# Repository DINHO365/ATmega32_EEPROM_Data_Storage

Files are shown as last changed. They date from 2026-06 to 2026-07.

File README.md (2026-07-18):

# ATmega32 EEPROM Data Logging and Configuration Storage System

Demonstrates internal EEPROM read/write on the ATmega32 by letting a
user increment/decrement a value in RAM, save it to EEPROM, read it
back, clear it, and recover it after reset or a power cycle.

## Repository structure

```
ATmega32_EEPROM_Data_Storage/
├── README.md
├── firmware/
│   ├── src/        button.c, display.c, eeprom_storage.c, indicator.c, lcd.c, main.c, uart.c
│   ├── include/    matching headers + config.h
│   └── hex/        firmware.hex / firmware.elf
├── kicad/
│   ├── schematic/  ATmega32_EEPROM_Storage.kicad_sch (+ project files), rendered PDF
│   ├── pcb/        ATmega32_EEPROM_Storage.kicad_pcb (+ project files), rendered PDF
│   └── gerber/     Gerber + drill (.drl) output
├── simulide/
│   ├── circuit/     EEPROM_Storage.sim1
│   └── screenshots/ test-run screenshots
├── documentation/
│   ├── block_diagram.png
│   ├── flowchart.png
│   ├── pin_mapping_table.md
│   ├── eeprom_address_table.md
│   ├── test_results.md
│   ├── erc_report.txt
│   └── drc_report.txt
└── media/
    └── demonstration_video.mp4
```

The schematic and PCB are kept in separate `kicad/schematic/` and
`kicad/pcb/` folders, each with its own copy of the KiCad project file
so either one opens directly in KiCad.

## Firmware

Source lives in `firmware/`, written in C for the ATmega32 at 8 MHz
(adjust `F_CPU` in `firmware/include/config.h` if a different clock is
used).

Build with avr-gcc:

```
cd firmware
make
```

(or open the `firmware/` folder as an MPLAB for VS Code project, using
the same source/include paths.)

### Behavior

| Action | Result |
|---|---|
| Power ON / OFF | Last value loaded from EEPROM and shown as CURRENT |
| INC button (PA0) | CURRENT increases (clamped at 255) |
| DEC button (PA1) | CURRENT decreases (clamped at 0) |
| SAVE button (PA2)  | CURRENT written to EEPROM; SAVE_LED + buzzer confirm |
| READ button (PA3)  | SAVED re-read from EEPROM and displayed |
| CLEAR button (PA4) | EEPROM and CURRENT reset to default (0); both LEDs + buzzer confirm |

Display output is a 16x2 HD44780 LCD (RS=PD4, RW=PD5, EN=PD6,
D4-D7=PC4-PC7 via the 16-pin header J1), showing:

```
CURRENT: 025
SAVED:   020
```

`DISPLAY_MODE` in `firmware/include/config.h` can be switched to
`DISPLAY_MODE_USART` to print the same values over USART (9600 baud,
8N1, PD1/TXD) for bench testing without an LCD attached.

### EEPROM layout

See [documentation/eeprom_address_table.md](documentation/eeprom_address_table.md).

### Pin mapping

See [documentation/pin_mapping_table.md](documentation/pin_mapping_table.md).

## SimulIDE simulation

`simulide/circuit/EEPROM_Storage.sim1` mirrors the KiCad PCB wiring
(4-bit LCD interface, RS/RW/EN on PD4-PD6, data lines on PC4-PC7) so
the same firmware behaves identically in simulation and on hardware.
Test results and screenshots for all required test cases are in
[documentation/test_results.md](documentation/test_results.md).

## KiCad design

Schematic and PCB pass ERC and DRC with no violations (see
`documentation/erc_report.txt` and `documentation/drc_report.txt`).
Gerber and drill files are in `kicad/gerber/`.

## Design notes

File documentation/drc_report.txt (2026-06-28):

** Drc report for ATmega32_EEPROM_Storage.kicad_pcb **
** Created on 2026-06-28T17:31:36 **
** Report includes: Errors, Warnings, Exclusions **

** Found 0 DRC violations **

** Found 0 unconnected pads **

** Found 0 Footprint errors **

** Ignored checks **
    - Footprint has no courtyard defined
    - Track endpoint not centered on via
    - Tuning profile track geometries
    - Footprint doesn't match symbol's footprint filters
    - Footprint component type doesn't match footprint pads

** End of Report **

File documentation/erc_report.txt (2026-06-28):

ERC report (2026-06-28T17:30:23, Encoding UTF8)
Report includes: Errors, Warnings, Exclusions

***** Sheet /

 ** ERC messages: 0  Errors 0  Warnings 0

 ** Ignored checks:
    - Global label only appears once in the schematic
    - Four connection points are joined together
    - SPICE model issue
    - Assigned footprint doesn't match footprint filters

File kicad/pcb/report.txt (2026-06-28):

Info: Processing symbol 'BZ1:Buzzer_Beeper:Buzzer_12x9.5RM7.6'.
Info: Processing symbol 'Q1:'.
Info: Processing symbol 'R4:Resistor_THT:R_Axial_DIN0207_L6.3mm_D2.5mm_P7.62mm_Horizontal'.
Info: Processing symbol 'C3:Capacitor_THT:C_Disc_D5.0mm_W2.5mm_P5.00mm'.
Info: Processing symbol 'ERROR_LED1:LED_THT:LED_D5.0mm'.
Info: Processing symbol 'R1:Resistor_THT:R_Axial_DIN0207_L6.3mm_D2.5mm_P7.62mm_Horizontal'.
Info: Processing symbol 'R3:Resistor_THT:R_Axial_DIN0207_L6.3mm_D2.5mm_P7.62mm_Horizontal'.
Info: Processing symbol 'R2:Resistor_THT:R_Axial_DIN0207_L6.3mm_D2.5mm_P7.62mm_Horizontal'.
Info: Processing symbol 'CLEAR1:Button_Switch_THT:SW_PUSH_6mm'.
Info: Processing symbol 'C2:Capacitor_THT:C_Disc_D5.0mm_W2.5mm_P5.00mm'.
Info: Processing symbol 'J1:'.
Info: Processing symbol 'C6:Capacitor_THT:C_Disc_D5.0mm_W2.5mm_P5.00mm'.
Info: Processing symbol 'D1:'.
Info: Processing symbol 'READ1:Button_Switch_THT:SW_PUSH_6mm'.
Info: Processing symbol 'C1:Capacitor_THT:C_Disc_D5.0mm_W2.5mm_P5.00mm'.
Info: Processing symbol 'C5:Capacitor_THT:C_Disc_D5.0mm_W2.5mm_P5.00mm'.
Info: Processing symbol 'DEC1:Button_Switch_THT:SW_PUSH_6mm'.
Info: Processing symbol 'INC1:Button_Switch_THT:SW_PUSH_6mm'.
Info: Processing symbol 'C4:Capacitor_THT:C_Disc_D5.0mm_W2.5mm_P5.00mm'.
Info: Processing symbol 'R5:Resistor_THT:R_Axial_DIN0207_L6.3mm_D2.5mm_P7.62mm_Horizontal'.
Info: Processing symbol 'RV1:'.
Info: Processing symbol 'SAVE1:Button_Switch_THT:SW_PUSH_6mm'.
Info: Processing symbol 'SAVE_LED1:LED_THT:LED_D5.0mm'.
Info: Processing symbol 'SW6:Button_Switch_THT:SW_PUSH_6mm'.
Info: Processing symbol 'U1:Package_DIP:DIP-40_W15.24mm'.
Info: Processing symbol 'Y1:Crystal:Crystal_HC49-U_Vertical'.
Updated BZ1 sheetfile to 'ATmega32_EEPROM_Storage.kicad_sch'.
Updated BZ1 footprint filters to '*Buzzer*'.
Add net Net-(BZ1--).
Connected BZ1 pin 2 to Net-(BZ1--).
Add net +5.
Connected BZ1 pin 1 to +5.
Updated BZ1 unit metadata.
Added C1 (footprint 'Capacitor_THT:C_Disc_D5.0mm_W2.5mm_P5.00mm').
Changed REF** reference designator to C1.
Changed C1 value from C_Disc_D5.0mm_W2.5mm_P5.00mm to 100nF.
Updated C1 symbol association from  to /24bfcb52-a1db-472c-bd11-8dc81d7c9061.
Updated C1 fields.
Updated C1 sheetname to '/'.
Updated C1 sheetfile to 'ATmega32_EEPROM_Storage.kicad_sch'.
Updated C1 footprint filters to 'C_*'.
Add net Net-(U1-AREF).
Connected C1 pin 2 to Net-(U1-AREF).
Add net GND.
Connected C1 pin 1 to GND.
Updated C1 unit metadata.
Added C2 (footprint 'Capacitor_THT:C_Disc_D5.0mm_W2.5mm_P5.00mm').
Changed REF** reference designator to C2.
Changed C2 value from C_Disc_D5.0mm_W2.5mm_P5.00mm to 100nF.
Updated C2 symbol association from  to /e254cf9d-e043-4f94-97bb-694d49c90928.
Updated C2 fields.
Updated C2 sheetname to '/'.
Updated C2 sheetfile to 'ATmega32_EEPROM_Storage.kicad_sch'.
Updated C2 footprint filters to 'C_*'.
Connected C2 pin 2 to +5.
Connected C2 pin 1 to GND.
Updated C2 unit metadata.
Added C3 (footprint 'Capacitor_THT:C_Disc_D5.0mm_W2.5mm_P5.00mm').
Changed REF** reference designator to C3.
Changed C3 value from C_Disc_D5.0mm_W2.5mm_P5.00mm to 22pF.
Updated C3 symbol association from  to /5f5ba432-2e26-45a8-8a6d-44987db70e49.
Updated C3 fields.
Updated C3 sheetname to '/'.
Updated C3 sheetfile to 'ATmega32_EEPROM_Storage.kicad_sch'.
Updated C3 footprint filters to 'C_*'.
Connected C3 pin 1 to GND.
Add net Net-(U1-XTAL1).
Connected C3 pin 2 to Net-(U1-XTAL1).
Updated C3 unit metadata.
Added C4 (footprint 'Capacitor_THT:C_Disc_D5.0mm_W2.5mm_P5.00mm').
Changed REF** reference designator to C4.
Changed C4 value from C_Disc_D5.0mm_W2.5mm_P5.00mm to 22pF.
Updated C4 symbol association from  to /1d878bed-edf5-4163-8b4c-c4068b8f29d9.
Updated C4 fields.
Updated C4 sheetname to '/'.
Updated C4 sheetfile to 'ATmega32_EEPROM_Storage.kicad_sch'.
Updated C4 footprint filters to 'C_*'.
Add net Net-(U1-XTAL2).
Connected C4 pin 2 to Net-(U1-XTAL2).
Connected C4 pin 1 to GND.
Updated C4 unit metadata.
Added C5 (footprint 'Capacitor_THT:C_Disc_D5.0mm_W2.5mm_P5.00mm').
Changed REF** reference designator to C5.
Changed C5 value from C_Disc_D5.0mm_W2.5mm_P5.00mm to 10µF.
Updated C5 symbol association from  to /0e762724-41b4-4da6-81d5-d80346a5db59.
Updated C5 fields.
Updated C5 sheetname to '/'.
Updated C5 sheetfile to 'ATmega32_EEPROM_Storage.kicad_sch'.
Updated C5 footprint filters to 'C_*'.
Connected C5 pin 2 to +5.
Connected C5 pin 1 to GND.
Updated C5 unit metadata.
Added C6 (footprint 'Capacitor_THT:C_Disc_D5.0mm_W2.5mm_P5.00mm').
Changed REF** reference designator to C6.
Changed C6 value from C_Disc_D5.0mm_W2.5mm_P5.00mm to 100nF.
Updated C6 symbol association from  to /9841b891-6f2c-46fd-a58e-c0312687f02c.
Updated C6 fields.
Updated C6 sheetname to '/'.
Updated C6 sheetfile to 'ATmega32_EEPROM_Storage.kicad_sch'.
Updated C6 footprint filters to 'C_*'.
Connected C6 pin 1 to GND.
Connected C6 pin 2 to +5.
Updated C6 unit metadata.
Added CLEAR1 (footprint 'Button_Switch_THT:SW_PUSH_6mm').
Changed REF** reference designator to CLEAR1.
Changed CLEAR1 value from SW_PUSH_6mm to SW_Push.
Updated CLEAR1 symbol association from  to /f9d98ad2-3187-4c4f-9837-3e64938a53d2.
Updated CLEAR1 fields.
Updated CLEAR1 sheetname to '/'.
Updated CLEAR1 sheetfile to 'ATmega32_EEPROM_Storage.kicad_sch'.
Connected CLEAR1 pin 1 to GND.
Add net Net-(U1-PA4).
Connected CLEAR1 pin 2 to Net-(U1-PA4).
Connected CLEAR1 pin 1 to GND.
Connected CLEAR1 pin 2 to Net-(U1-PA4).
Updated CLEAR1 unit metadata.
Added DEC1 (footprint 'Button_Switch_THT:SW_PUSH_6mm').
Changed REF** reference designator to DEC1.
Changed DEC1 value from SW_PUSH_6mm to SW_Push.
Updated DEC1 symbol association from  to /e86158a6-d8b5-44fe-8d50-56f265a3bca7.
Updated DEC1 fields.
Updated DEC1 sheetname to '/'.
Updated DEC1 sheetfile to 'ATmega32_EEPROM_Storage.kicad_sch'.
Connected DEC1 pin 1 to GND.
Connected DEC1 pin 1 to GND.
Add net Net-(U1-PA1).
Connected DEC1 pin 2 to Net-(U1-PA1).
Connected DEC1 pin 2 to Net-(U1-PA1).
Updated DEC1 unit metadata.
Added ERROR_LED1 (footprint 'LED_THT:LED_D5.0mm').
Changed REF** reference designator to ERROR_LED1.
Changed ERROR_LED1 value from LED_D5.0mm to LED.
Updated ERROR_LED1 symbol association from  to /03e158cb-828b-4738-9a32-4cf614b0b1c2.
Updated ERROR_LED1 fields.
Updated ERROR_LED1 sheetname to '/'.
Updated ERROR_LED1 sheetfile to 'ATmega32_EEPROM_Storage.kicad_sch'.
Updated ERROR_LED1 footprint filters to 'LED* LED_SMD:* LED_THT:*'.
Add net Net-(ERROR_LED1-K).
Connected ERROR_LED1 pin 1 to Net-(ERROR_LED1-K).
Connected ERROR_LED1 pin 2 to GND.
Updated ERROR_LED1 unit metadata.
Added INC1 (footprint 'Button_Switch_THT:SW_PUSH_6mm').
Changed REF** reference designator to INC1.
Changed INC1 value from SW_PUSH_6mm to SW_Push.
Updated INC1 symbol association from  to /20042b9c-9d53-4315-aa2c-4964038f320a.
Updated INC1 fields.
Updated INC1 sheetname to '/'.
Updated INC1 sheetfile to 'ATmega32_EEPROM_Storage.kicad_sch'.
Add net Net-(U1-PA0).
Connected INC1 pin 2 to Net-(U1-PA0).
Connected INC1 pin 2 to Net-(U1-PA0).
Connected INC1 pin 1 to GND.
Connected INC1 pin 1 to GND.
Updated INC1 unit metadata.
Added R1 (footprint 'Resistor_THT:R_Axial_DIN0207_L6.3mm_D2.5mm_P7.62mm_Horizontal').
Changed REF** reference designator to R1.
Changed R1 value from R_Axial_DIN0207_L6.3mm_D2.5mm_P7.62mm_Horizontal to 220 Ω.
Updated R1 symbol association from  to /25846952-49a7-47c7-8c63-a150eebb852f.
Updated R1 fields.
Updated R1 sheetname to '/'.
Updated R1 sheetfile to 'ATmega32_EEPROM_Storage.kicad_sch'.
Updated R1 footprint filters to 'R_*'.
Add net Net-(SAVE_LED1-K).
Connected R1 pin 2 to Net-(SAVE_LED1-K).
Add net Net-(U1-PB0).
Connected R1 pin 1 to Net-(U1-PB0).
Updated R1 unit metadata.
Added R2 (footprint 'Resistor_THT:R_Axial_DIN0207_L6.3mm_D2.5mm_P7.62mm_Horizontal').
Changed REF** reference designator to R2.
Changed R2 value from R_Axial_DIN0207_L6.3mm_D2.5mm_P7.62mm_Horizontal to 220 Ω.
Updated R2 symbol association from  to /aefaf649-2aac-44a9-b6a8-29b3fd2b7f1c.
Updated R2 fields.
Updated R2 sheetname to '/'.
Updated R2 sheetfile to 'ATmega32_EEPROM_Storage.kicad_sch'.
Updated R2 footprint filters to 'R_*'.
Add net Net-(U1-PB1).
Connected R2 pin 1 to Net-(U1-PB1).
Connected R2 pin 2 to Net-(ERROR_LED1-K).
Updated R2 unit metadata.
Added R3 (footprint 'Resistor_THT:R_Axial_DIN0207_L6.3mm_D2.5mm_P7.62mm_Horizontal').
Changed REF** reference designator to R3.
Changed R3 value from R_Axial_DIN0207_L6.3mm_D2.5mm_P7.62mm_Horizontal to 10K.
Updated R3 symbol association from  to /a99e0ae9-cf5f-46ae-966e-9f08fff450c3.
Updated R3 fields.
Updated R3 sheetname to '/'.
Updated R3 sheetfile to 'ATmega32_EEPROM_Storage.kicad_sch'.
Updated R3 footprint filters to 'R_*'.
Connected R3 pin 1 to +5.
Add net Net-(U1-~{RESET}).
Connected R3 pin 2 to Net-(U1-~{RESET}).
Updated R3 unit metadata.
Added R4 (footprint 'Resistor_THT:R_Axial_DIN0207_L6.3mm_D2.5mm_P7.62mm_Horizontal').
Changed REF** reference designator to R4.
Changed R4 value from R_Axial_DIN0207_L6.3mm_D2.5mm_P7.62mm_Horizontal to 1K.
Updated R4 symbol association from  to /8c8e0ea6-d48a-435d-a58e-93637bdbd6fa.
Updated R4 fields.
Updated R4 sheetname to '/'.
Updated R4 sheetfile to 'ATmega32_EEPROM_Storage.kicad_sch'.
Updated R4 footprint filters to 'R_*'.
Add net Net-(U1-PB2).
Connected R4 pin 1 to Net-(U1-PB2).
Add net Net-(Q1-B).
Connected R4 pin 2 to Net-(Q1-B).
Updated R4 unit metadata.
Added R5 (footprint 'Resistor_THT:R_Axial_DIN0207_L6.3mm_D2.5mm_P7.62mm_Horizontal').
Changed REF** reference designator to R5.
Changed R5 value from R_Axial_DIN0207_L6.3mm_D2.5mm_P7.62mm_Horizontal to 33 Ω.
Updated R5 symbol association from  to /6cdbeba3-d8a7-4b60-be25-00a370c620dc.
Updated R5 fields.
Updated R5 sheetname to '/'.
Updated R5 sheetfile to 'ATmega32_EEPROM_Storage.kicad_sch'.
Updated R5 footprint filters to 'R_*'.
Add net Net-(J1-Pin_15).
Connected R5 pin 2 to Net-(J1-Pin_15).
Connected R5 pin 1 to +5.
Updated R5 unit metadata.
Added READ1 (footprint 'Button_Switch_THT:SW_PUSH_6mm').
Changed REF** reference designator to READ1.
Changed READ1 value from SW_PUSH_6mm to SW_Push.
Updated READ1 symbol association from  to /5ea2faad-7d2b-4ffe-926f-460adb47186b.
Updated READ1 fields.
Updated READ1 sheetname to '/'.
Updated READ1 sheetfile to 'ATmega32_EEPROM_Storage.kicad_sch'.
Add net Net-(U1-PA3).
Connected READ1 pin 2 to Net-(U1-PA3).
Connected READ1 pin 2 to Net-(U1-PA3).
Connected READ1 pin 1 to GND.
Connected READ1 pin 1 to GND.
Updated READ1 unit metadata.
Added BZ1 (footprint 'Buzzer_Beeper:Buzzer_12x9.5RM7.6').
Changed REF** reference designator to BZ1.
Added SAVE1 (footprint 'Button_Switch_THT:SW_PUSH_6mm').
Changed REF** reference designator to SAVE1.
Changed SAVE1 value from SW_PUSH_6mm to SW_Push.
Updated SAVE1 symbol association from  to /aa2ea0c0-ae05-4af6-8a99-f9b31aa69a28.
Updated SAVE1 fields.
Updated SAVE1 sheetname to '/'.
Updated SAVE1 sheetfile to 'ATmega32_EEPROM_Storage.kicad_sch'.
Add net Net-(U1-PA2).
Connected SAVE1 pin 2 to Net-(U1-PA2).
Connected SAVE1 pin 1 to GND.
Connected SAVE1 pin 2 to Net-(U1-PA2).
Connected SAVE1 pin 1 to GND.
Updated SAVE1 unit metadata.
Changed BZ1 value from Buzzer_12x9.5RM7.6 to Buzzer.
Added SAVE_LED1 (footprint 'LED_THT:LED_D5.0mm').
Changed REF** reference designator to SAVE_LED1.
Changed SAVE_LED1 value from LED_D5.0mm to LED.
Updated SAVE_LED1 symbol association from  to /df7bb9b5-a601-405f-a89e-340b0aa88f51.
Updated SAVE_LED1 fields.
Updated SAVE_LED1 sheetname to '/'.
Updated SAVE_LED1 sheetfile to 'ATmega32_EEPROM_Storage.kicad_sch'.
Updated SAVE_LED1 footprint filters to 'LED* LED_SMD:* LED_THT:*'.
Connected SAVE_LED1 pin 2 to GND.
Connected SAVE_LED1 pin 1 to Net-(SAVE_LED1-K).
Updated SAVE_LED1 unit metadata.
Updated BZ1 symbol association from  to /de0766b6-4bf1-4921-b813-c11837fbc788.
Added SW6 (footprint 'Button_Switch_THT:SW_PUSH_6mm').
Changed REF** reference designator to SW6.
Changed SW6 value from SW_PUSH_6mm to SW_Push.
Updated SW6 symbol association from  to /44e3c206-02d5-4e98-98ad-dfd872349ed3.
Updated SW6 fields.
Updated SW6 sheetname to '/'.
Updated SW6 sheetfile to 'ATmega32_EEPROM_Storage.kicad_sch'.
Connected SW6 pin 2 to +5.
Connected SW6 pin 1 to GND.
Connected SW6 pin 1 to GND.
Connected SW6 pin 2 to +5.
Updated SW6 unit metadata.
Updated BZ1 fields.
Added U1 (footprint 'Package_DIP:DIP-40_W15.24mm').
Changed REF** reference designator to U1.
Changed U1 value from DIP-40_W15.24mm to ATmega32-16P.
Updated U1 symbol association from  to /f4b6e0bf-be70-449e-be25-8a7d1761b35b.
Updated U1 fields.
Updated U1 sheetname to '/'.
Updated U1 sheetfile to 'ATmega32_EEPROM_Storage.kicad_sch'.
Updated U1 footprint filters to 'DIP*W15.24mm*'.
Add net unconnected-(U1-PC0-Pad22).
Connected U1 pin 22 to unconnected-(U1-PC0-Pad22).
Add net unconnected-(U1-PB5-Pad6).
Connected U1 pin 6 to unconnected-(U1-PB5-Pad6).
Add net unconnected-(U1-PB6-Pad7).
Connected U1 pin 7 to unconnected-(U1-PB6-Pad7).
Connected U1 pin 36 to Net-(U1-PA4).
Add net Net-(J1-Pin_12).
Connected U1 pin 27 to Net-(J1-Pin_12).
Connected U1 pin 31 to GND.
Connected U1 pin 3 to Net-(U1-PB2).
Add net unconnected-(U1-PD0-Pad14).
Connected U1 pin 14 to unconnected-(U1-PD0-Pad14).
Add net unconnected-(U1-PD1-Pad15).
Connected U1 pin 15 to unconnected-(U1-PD1-Pad15).
Add net Net-(J1-Pin_5).
Connected U1 pin 19 to Net-(J1-Pin_5).
Add net unconnected-(U1-PD3-Pad17).
Connected U1 pin 17 to unconnected-(U1-PD3-Pad17).
Add net unconnected-(U1-PA7-Pad33).
Connected U1 pin 33 to unconnected-(U1-PA7-Pad33).
Add net unconnected-(U1-PD7-Pad21).
Connected U1 pin 21 to unconnected-(U1-PD7-Pad21).
Connected U1 pin 10 to +5.
Add net unconnected-(U1-PB3-Pad4).
Connected U1 pin 4 to unconnected-(U1-PB3-Pad4).
Connected U1 pin 37 to Net-(U1-PA3).
Connected U1 pin 38 to Net-(U1-PA2).
Connected U1 pin 13 to Net-(U1-XTAL1).
Add net Net-(J1-Pin_11).
Connected U1 pin 26 to Net-(J1-Pin_11).
Connected U1 pin 30 to +5.
Add net Net-(J1-Pin_14).
Connected U1 pin 29 to Net-(J1-Pin_14).
Add net unconnected-(U1-PC3-Pad25).
Connected U1 pin 25 to unconnected-(U1-PC3-Pad25).
Connected U1 pin 40 to Net-(U1-PA0).
Connected U1 pin 1 to Net-(U1-PB0).
Connected U1 pin 12 to Net-(U1-XTAL2).
Connected U1 pin 11 to GND.
Add net Net-(J1-Pin_4).
Connected U1 pin 18 to Net-(J1-Pin_4).
Add net unconnected-(U1-PA6-Pad34).
Connected U1 pin 34 to unconnected-(U1-PA6-Pad34).
Connected U1 pin 39 to Net-(U1-PA1).
Connected U1 pin 2 to Net-(U1-PB1).
Add net unconnected-(U1-PC2-Pad24).
Connected U1 pin 24 to unconnected-(U1-PC2-Pad24).
Add net unconnected-(U1-PD2-Pad16).
Connected U1 pin 16 to unconnected-(U1-PD2-Pad16).
Connected U1 pin 9 to Net-(U1-~{RESET}).
Add net unconnected-(U1-PB7-Pad8).
Connected U1 pin 8 to unconnected-(U1-PB7-Pad8).
Connected U1 pin 32 to Net-(U1-AREF).
Add net unconnected-(U1-PC1-Pad23).
Connected U1 pin 23 to unconnected-(U1-PC1-Pad23).
Add net Net-(J1-Pin_6).
Connected U1 pin 20 to Net-(J1-Pin_6).
Add net Net-(J1-Pin_13).
Connected U1 pin 28 to Net-(J1-Pin_13).
Add net unconnected-(U1-PB4-Pad5).
Connected U1 pin 5 to unconnected-(U1-PB4-Pad5).
Add net unconnected-(U1-PA5-Pad35).
Connected U1 pin 35 to unconnected-(U1-PA5-Pad35).
Updated U1 unit metadata.
Updated BZ1 sheetname to '/'.
Added Y1 (footprint 'Crystal:Crystal_HC49-U_Vertical').
Changed REF** reference designator to Y1.
Changed Y1 value from Crystal_HC49-U_Vertical to 16MHz.
Updated Y1 symbol association from  to /7d55f320-9426-416c-ad1c-54ae5ae9aaff.
Updated Y1 fields.
Updated Y1 sheetname to '/'.
Updated Y1 sheetfile to 'ATmega32_EEPROM_Storage.kicad_sch'.
Updated Y1 footprint filters to 'Crystal*'.
Connected Y1 pin 2 to Net-(U1-XTAL1).
Connected Y1 pin 1 to Net-(U1-XTAL2).
Updated Y1 unit metadata.
Error: Cannot add Q1 (no footprint assigned).
Error: Cannot add J1 (no footprint assigned).
Error: Cannot add RV1 (no footprint assigned).
Error: Cannot add D1 (no footprint assigned).

Info: Total warnings: 0, errors: 4.

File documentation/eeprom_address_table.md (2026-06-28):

# EEPROM Address Table

| Address (hex) | Size | Content | Written By | Read By |
|---|---|---|---|---|
| 0x00 | 1 byte  | Magic/init byte (`0xAA` once initialized) | `EEPROM_Storage_Init`, `EEPROM_SaveValue`, `EEPROM_ClearValue` | `EEPROM_Storage_Init` (first-boot detection) |
| 0x01 | 1 byte  | Saved configuration value (0-255) | `EEPROM_SaveValue`, `EEPROM_ClearValue` | `EEPROM_LoadValue` (on startup and on Read button) |

## Magic byte rationale

Unprogrammed/erased EEPROM cells read back as `0xFF`. Without a sentinel,
the very first power-up would load `255` as if it were a valid saved
value. `EEPROM_Storage_Init()` checks address `0x00` for `0xAA`; if it is
not present, it writes the default value (`0`) to address `0x01` and
stamps the magic byte, guaranteeing a well-defined first-run state.

## Extension task reservation

If the optional "store multiple records" extension is implemented, the
record array can start at address `0x02` (e.g. 5 records x 1 byte =
addresses `0x02`-`0x06`), with a separate index byte for the
currently-selected record. This is not required for the base assignment
and is not implemented in the current firmware.

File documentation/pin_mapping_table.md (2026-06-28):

# ATmega32 Pin Mapping Table

| ATmega32 Pin / Resource | Function | Connected Device | Firmware Macro |
|---|---|---|---|
| Internal EEPROM | Non-volatile storage | Stores saved value | `EEPROM_ADDR_VALUE`, `EEPROM_ADDR_MAGIC` |
| PA0 | Digital input  | Increment button | `BTN_INC` |
| PA1 | Digital input  | Decrement button | `BTN_DEC` |
| PA2 | Digital input  | Save button | `BTN_SAVE` |
| PA3 | Digital input  | Read button | `BTN_READ` |
| PA4 | Digital input  | Clear button | `BTN_CLEAR` |
| PB0 | Digital output | Save / status LED | `SAVE_LED` |
| PB1 | Digital output | Error LED | `ERROR_LED` |
| PB2 | Digital output | Buzzer (via R4 + NPN driver transistor Q1) | `BUZZER` |
| PD4 | Digital output | LCD RS (J1 pin 4) | `LCD_RS` |
| PD5 | Digital output | LCD RW (J1 pin 5, held low) | `LCD_RW` |
| PD6 | Digital output | LCD EN (J1 pin 6) | `LCD_EN` |
| PC4-PC7 | Digital output | LCD D4-D7 (J1 pins 11-14) | `LCD_D4..LCD_D7` |
| PD0 / RXD, PD1 / TXD | unused on this board | not wired to anything (no serial header on the actual PCB) | n/a |

J1 is a standard 16-pin HD44780 header: pin 1=GND, pin 2=+5V, pin
3=VEE (contrast, via potentiometer RV1), pins 7-10=GND (D0-D3, unused
in 4-bit mode), pin 15=LED+ (via resistor R5), pin 16=LED- (GND).

DDR configuration used by the firmware:

```
DDRA = 0x00   // PORTA: all 5 buttons as inputs (internal pull-ups enabled)
DDRB = 0x07   // PB0 (SAVE_LED), PB1 (ERROR_LED), PB2 (BUZZER) as outputs
DDRC |= 0xF0  // PC4-PC7: LCD D4-D7 as outputs
DDRD |= 0x70  // PD4-PD6: LCD RS/RW/EN as outputs
```

Display backend is selected at compile time in `firmware/include/config.h`
via `DISPLAY_MODE` (`DISPLAY_MODE_USART` or `DISPLAY_MODE_LCD`).

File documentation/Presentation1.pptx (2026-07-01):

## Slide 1

ATmega32 EEPROM-Based Data Logging
and Configuration Storage System

Internal EEPROM Read/Write Operation on the ATmega32 Microcontroller

Group Project Presentation

Course : CT 321

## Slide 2

Group Members

Students Name | Registration Numbers
SALIMA ABDI MFAUME | T23-03-09616
EDNA SAMWEL DIDAS | T23-03-09544
DENIS RICHARD SOWANI | T23-03-12706
KARIMU JOSEPH MKIYA | T23-03-15224

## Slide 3

Problem Statement

● Embedded systems often need to remember information even after power is switched OFF
● Examples: saved threshold values, calibration settings, user preferences, event counts, alarm limits, configuration data
● Ordinary RAM loses its contents when power is removed
● The ATmega32's internal EEPROM can retain stored data without external power
● This project demonstrates EEPROM read/write operation through a practical data logging and configuration storage system

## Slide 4

Project Objective

● Design and implement an EEPROM-based data logging and configuration storage system
● Use the ATmega32 internal EEPROM, push buttons, LEDs, buzzer, and an LCD display
● Allow the user to increase, decrease, save, read, and clear a stored value
● Ensure the stored value remains available after reset or power cycling

User Value -> EEPROM Write -> Power-Off Retention -> EEPROM Read

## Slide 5

Expected System Operation

Input / User Action | Expected Output
System powered ON | Last saved value is loaded from EEPROM
Increment button pressed | Current value increases
Decrement button pressed | Current value decreases
Save button pressed | Current value is written to EEPROM
Read button pressed | Stored value is displayed
Clear button pressed | EEPROM value is reset to default
Reset button pressed | System restarts and reloads stored value
Power switched OFF then ON | Last saved value is recovered

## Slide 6

Main Hardware Components

Component | Qty | Purpose
ATmega32 microcontroller | 1 | Main controller and internal EEPROM device
LCD module (16x2 HD44780) | 1 | Displays current and stored values
Push buttons | 6 | Increment, decrement, save, read, clear + reset
LEDs | 2 | Save and error/status indication
Current-limiting resistors | 2 | LED protection
Buzzer + NPN driver transistor | 1 | Save confirmation / error alert
Reset push button + pull-up resistor | 1 | Manual microcontroller reset
Crystal oscillator + capacitors | 1 | 8 MHz clock source
Power supply | 1 | 5 V regulated supply

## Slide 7

ATmega32 Pin Mapping

Pin / Resource | Function | Connected Device
Internal EEPROM | Non-volatile storage | Stores saved value
PA0 - PA4 | Digital input | INC / DEC / SAVE / READ / CLEAR buttons
PB0 | Digital output | SAVE / status LED
PB1 | Digital output | ERROR LED
PB2 | Digital output | Buzzer (via NPN driver transistor)
PD4 / PD5 / PD6 | Digital output | LCD RS / RW / EN
PC4 - PC7 | Digital output | LCD D4 - D7 (4-bit mode)
RESET pin | Reset input | Reset push button + 10 kΩ pull-up

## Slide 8

System Block Diagram

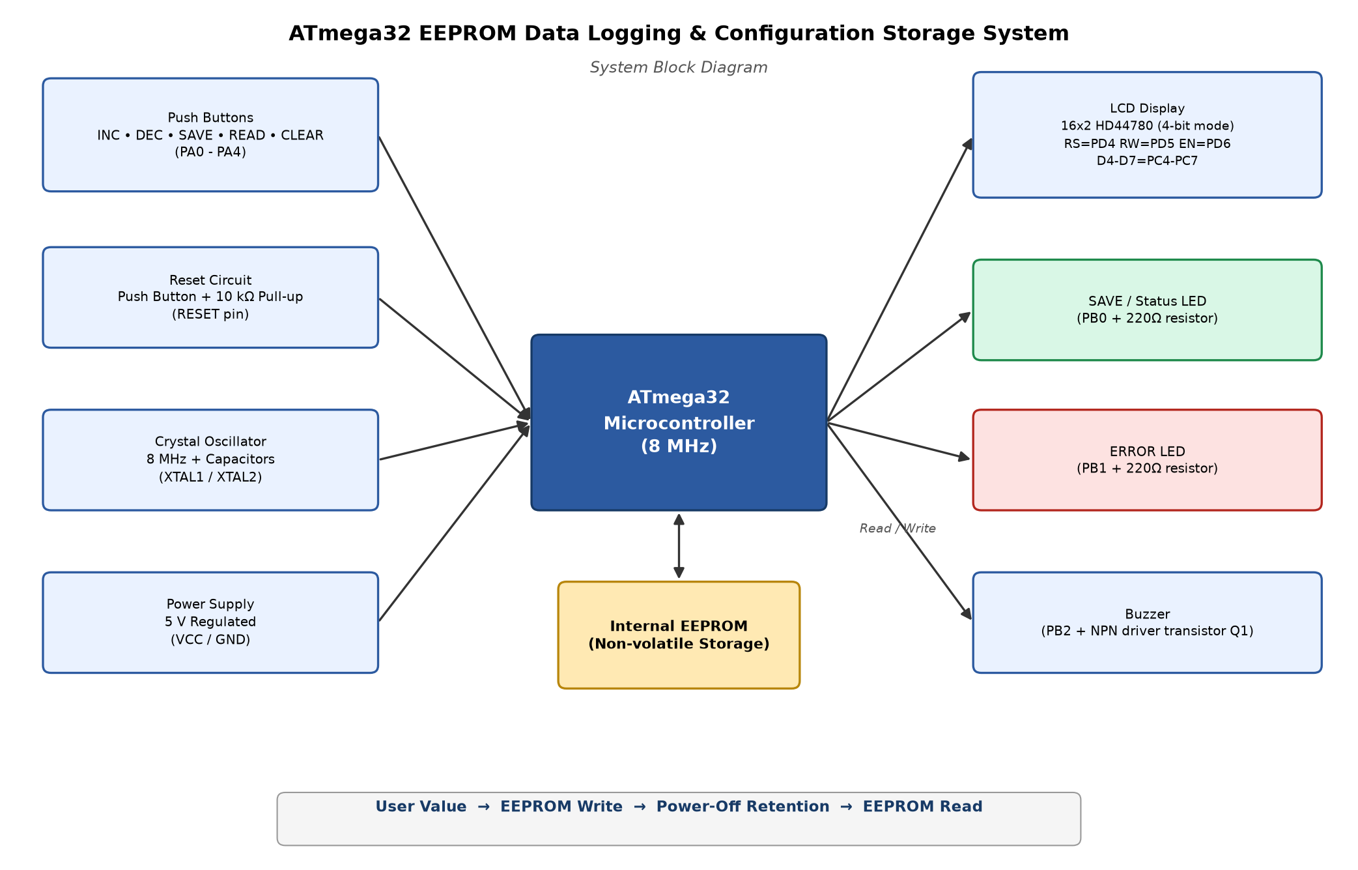
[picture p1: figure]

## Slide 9

Firmware Flowchart

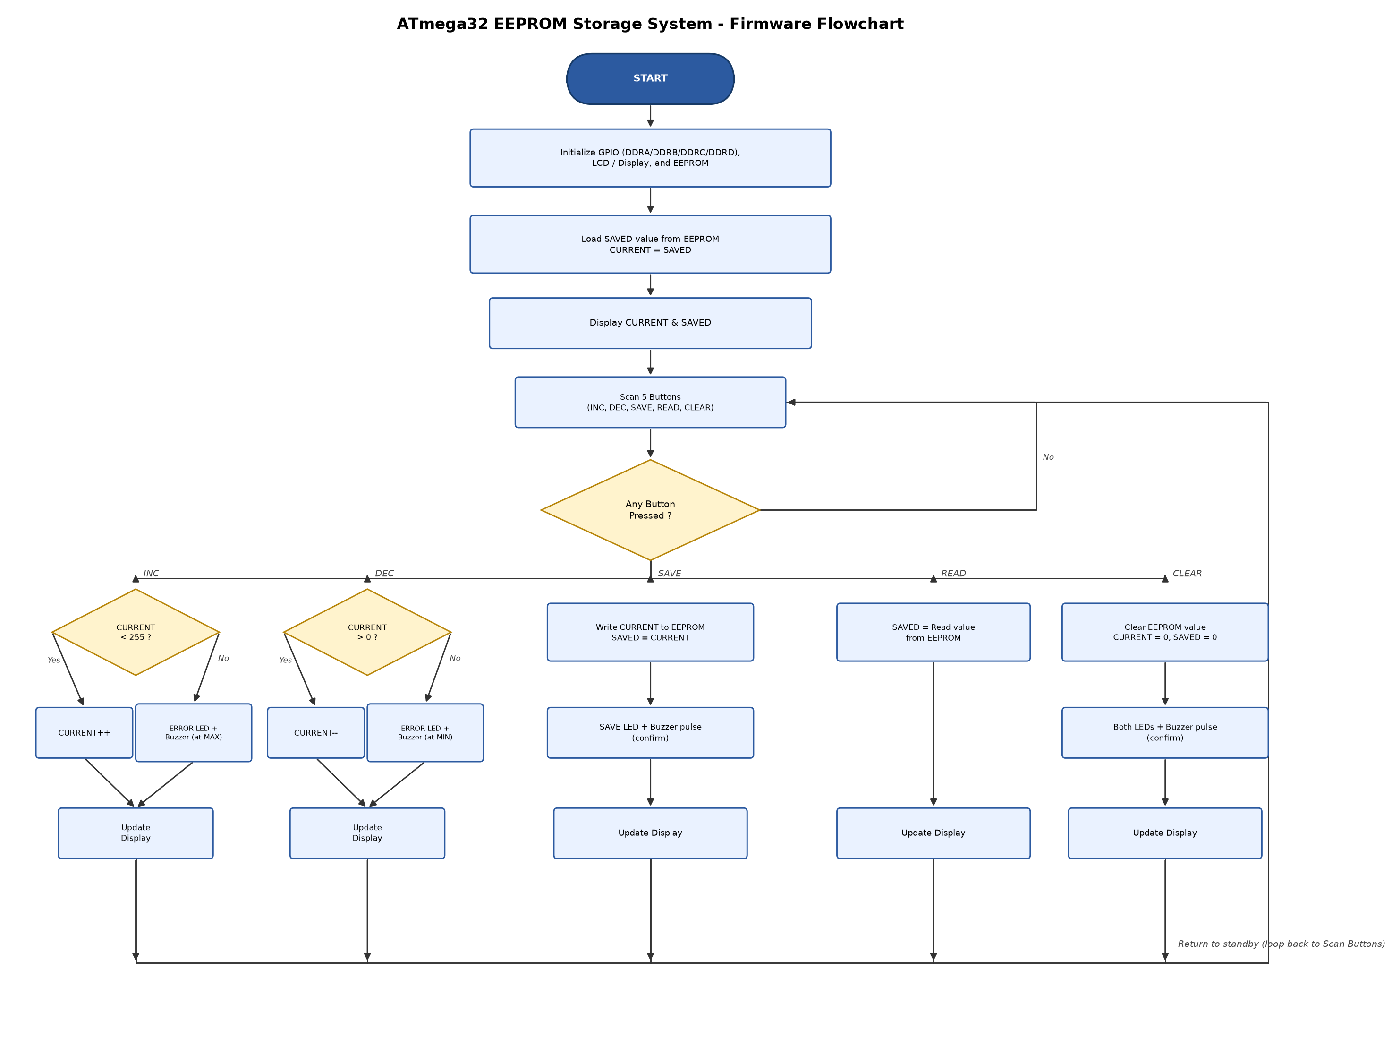
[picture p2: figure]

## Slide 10

EEPROM Address Map

A magic byte distinguishes a blank (erased) EEPROM, which reads as 0xFF, from a genuinely saved value

Address | Size | Content
0x00 | 1 byte | Magic / init byte (0xAA once initialized)
0x01 | 1 byte | Saved configuration value (0 - 255)

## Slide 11

KiCad Schematic Design

0 ERC violations

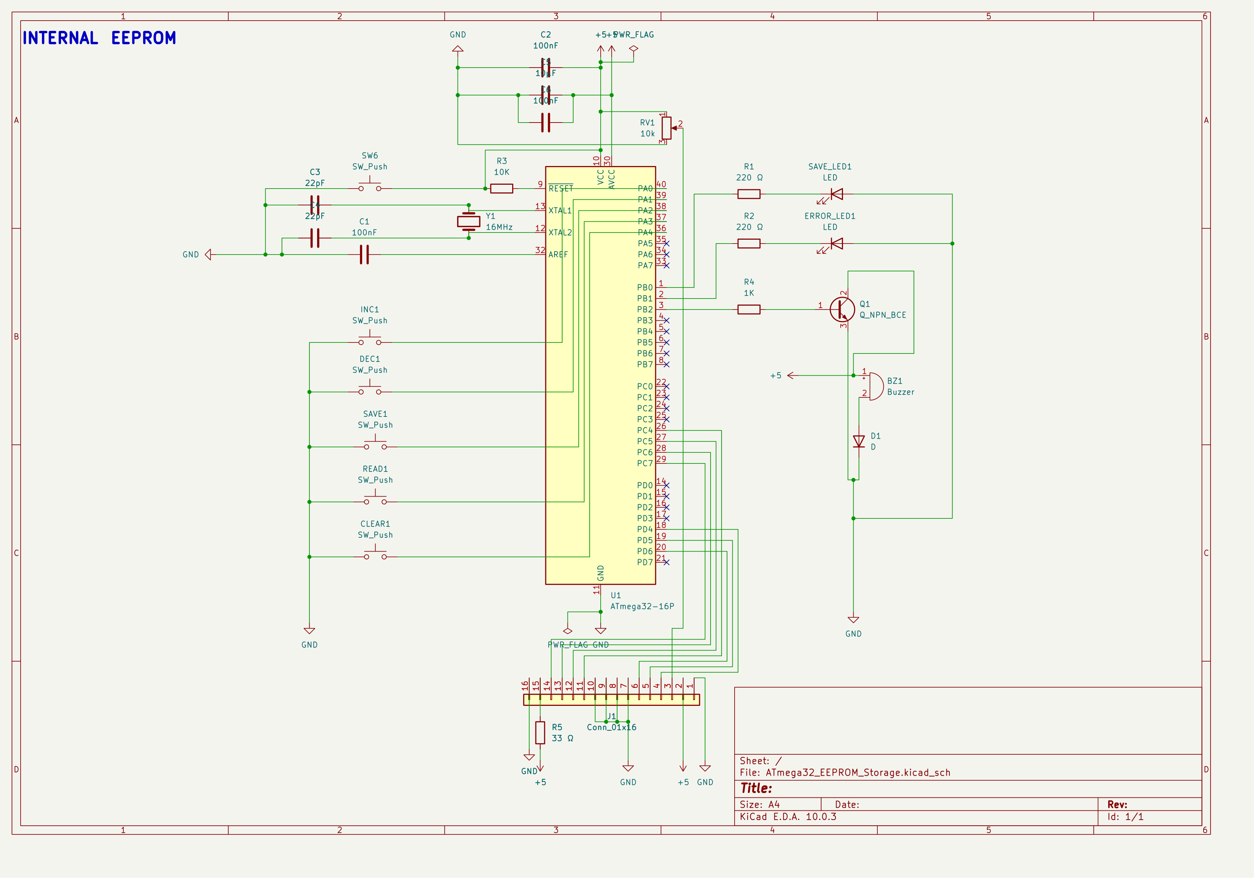
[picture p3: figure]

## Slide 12

KiCad PCB Layout

0 DRC violations, 0 unconnected nets

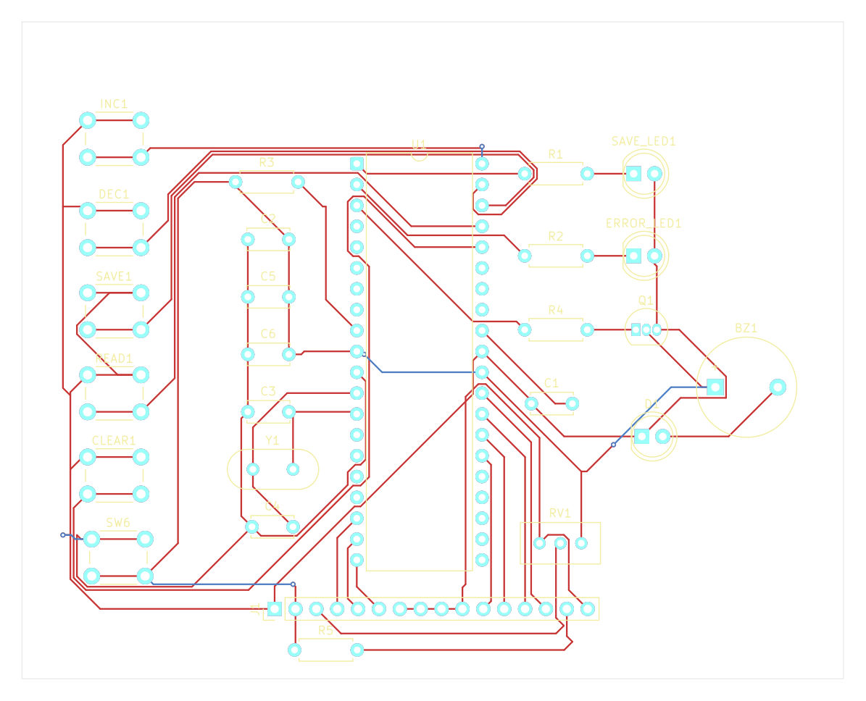
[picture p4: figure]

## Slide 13

SimulIDE Simulation - Startup

System loads the last saved value from EEPROM on power-up

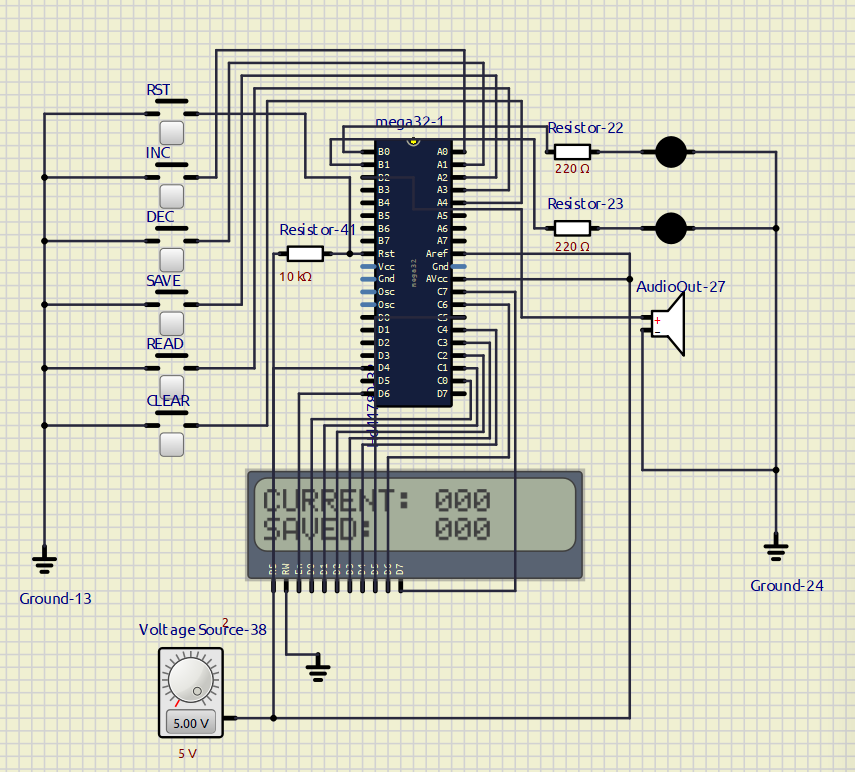
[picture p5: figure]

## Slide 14

SimulIDE Simulation - Save & Read

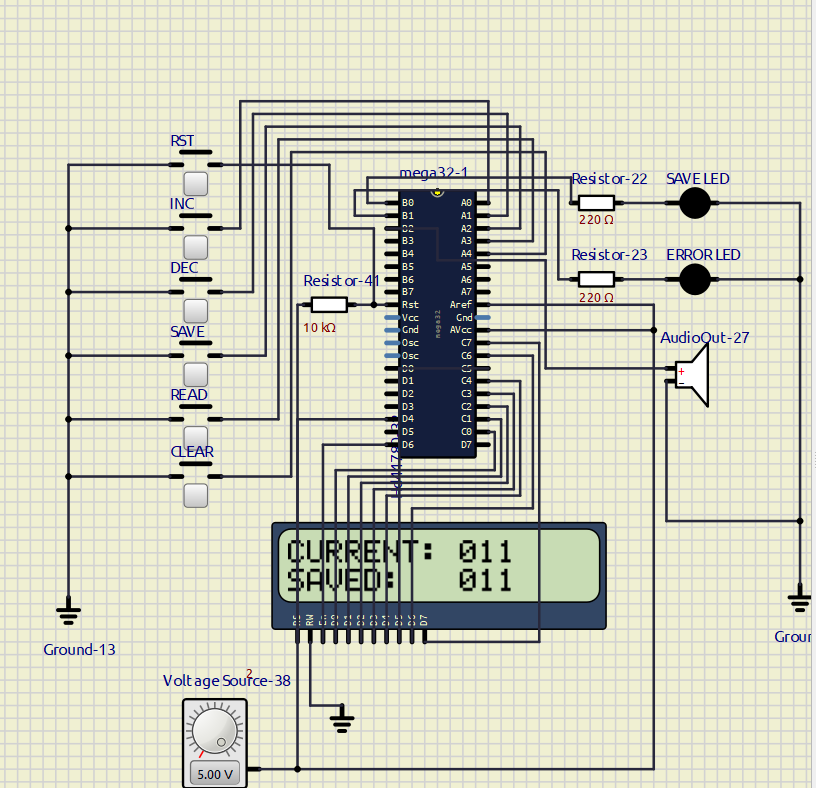
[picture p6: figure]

SAVE: current value written to EEPROM

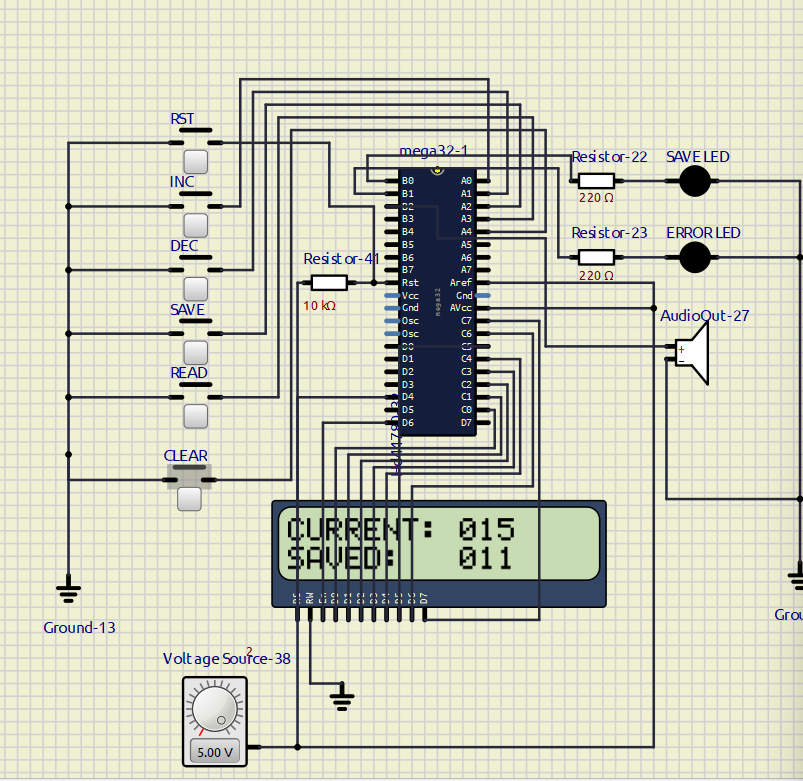
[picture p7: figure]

READ: stored value re-read from EEPROM

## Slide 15

Test Results Summary

All 8 functional test cases passed in SimulIDE

Test Case | Result
Startup (first power-up) | PASS - CURRENT: 000, SAVED: 000
Increment | PASS - clamps correctly at 255
Decrement | PASS - clamps correctly at 0
Save | PASS - SAVED updates to match CURRENT
Read | PASS - SAVED re-read independently from EEPROM
Clear | PASS - both values reset to 000
Reset recovery | PASS - last saved value reloaded
Power-cycle recovery | PASS - last saved value recovered

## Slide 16

Extension Task (Optional)

● Store multiple records instead of a single value
● Example: last five event-count values or threshold settings
● User scrolls through stored records using buttons or serial commands
● Requires careful EEPROM address management and simple record indexing in software

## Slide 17

Conclusion

● Successfully implemented EEPROM read/write operations on the ATmega32
● Designed and verified a complete schematic and PCB in KiCad (0 ERC/DRC violations)
● Built and tested firmware controlling buttons, LCD, LEDs, and buzzer
● Validated complete system behavior in SimulIDE - all test cases passed
● Demonstrated reliable data retention across reset and power cycling

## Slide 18

Thank You

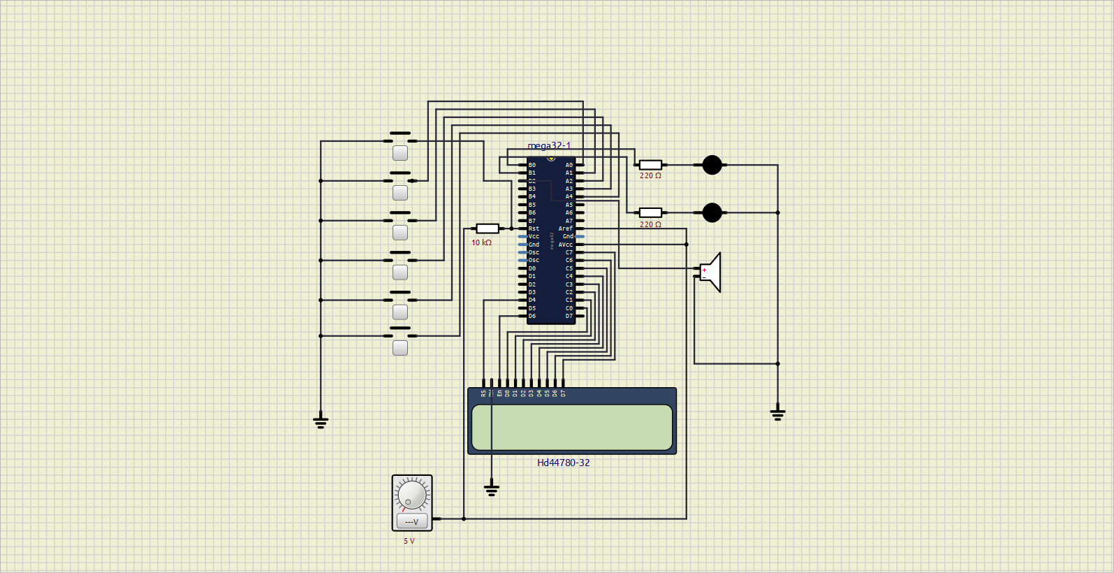
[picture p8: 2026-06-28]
simulide/screenshots/EEPROM_Storage.png

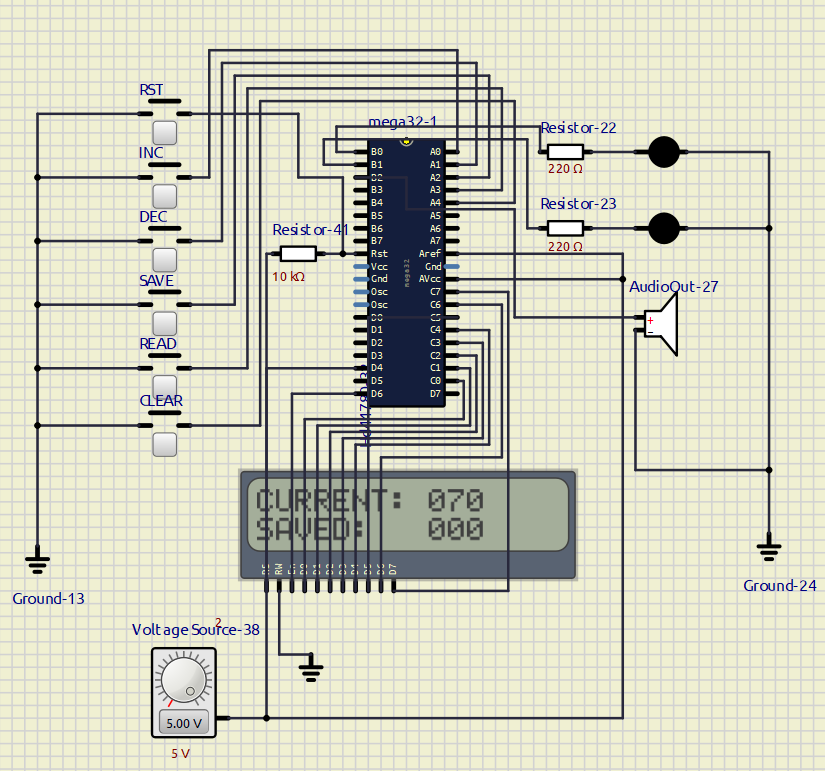
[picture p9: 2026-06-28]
simulide/screenshots/02_increment.png

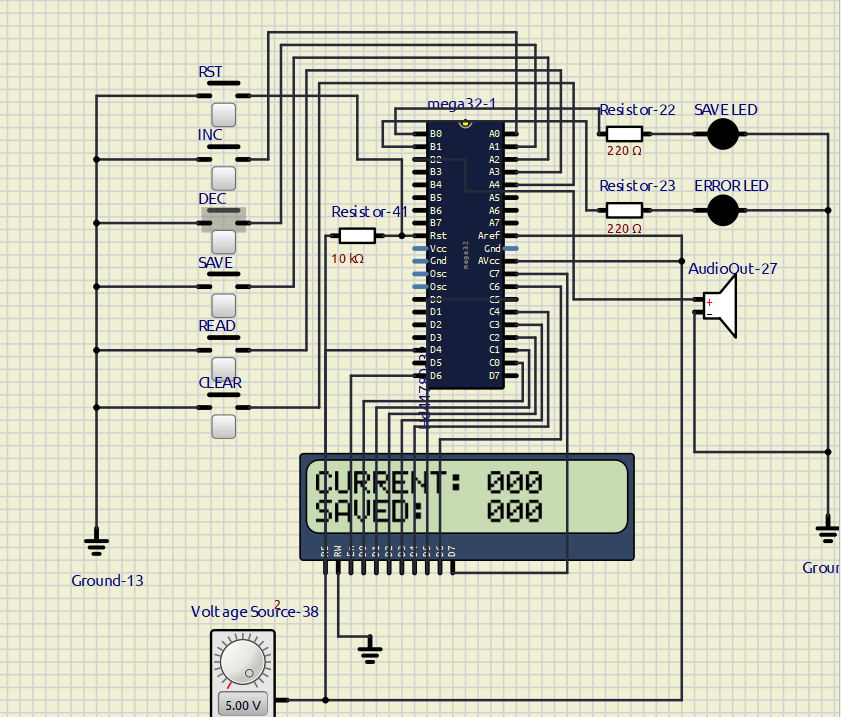
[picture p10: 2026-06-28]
simulide/screenshots/03_decrement.png

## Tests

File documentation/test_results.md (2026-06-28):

# EEPROM Test Results

Tested in SimulIDE using `simulide/circuit/EEPROM_Storage.sim1` with
`firmware/hex/firmware.hex` loaded into the `mega32-1` MCU component.

| Test Case | Action | Expected Result | Observed Result | Screenshot |
|---|---|---|---|---|
| Startup (first power-up) | Power ON with blank EEPROM | CURRENT: 000, SAVED: 000 | PASS — LCD showed `CURRENT: 000` / `SAVED: 000` | [01_startup.png](../simulide/screenshots/01_startup.png) |
| Increment | Press INC button x N | CURRENT increases by 1 per press, stops at 255 | PASS — CURRENT increased correctly with each press; clamps at 255 without wraparound | [02_increment.png](../simulide/screenshots/02_increment.png) |
| Decrement | Press DEC button x N | CURRENT decreases by 1 per press, stops at 0 | PASS — CURRENT decreased correctly with each press; clamps at 0 without wraparound | [03_decrement.png](../simulide/screenshots/03_decrement.png) |
| Save | Press SAVE button | SAVE_LED + buzzer pulse, SAVED == CURRENT | PASS — SAVED updated to match CURRENT | [04_save.png](../simulide/screenshots/04_save.png) |
| Read | Press READ button | SAVED value re-read from EEPROM and displayed | PASS — SAVED correctly re-read from EEPROM independent of any unsaved CURRENT changes | [05_read.png](../simulide/screenshots/05_read.png) |
| Clear | Press CLEAR button | Both LEDs + buzzer pulse, CURRENT and SAVED reset to 000 | PASS — both values reset to 000 | — |
| Reset recovery | Press RST button | SAVED value from EEPROM reloaded as CURRENT | PASS — CURRENT correctly reloaded from the last saved EEPROM value, discarding any unsaved changes | — |
| Power-cycle recovery | Stop simulation, then Play again | Last saved value recovered | PASS — last saved value recovered after the power cycle | — |

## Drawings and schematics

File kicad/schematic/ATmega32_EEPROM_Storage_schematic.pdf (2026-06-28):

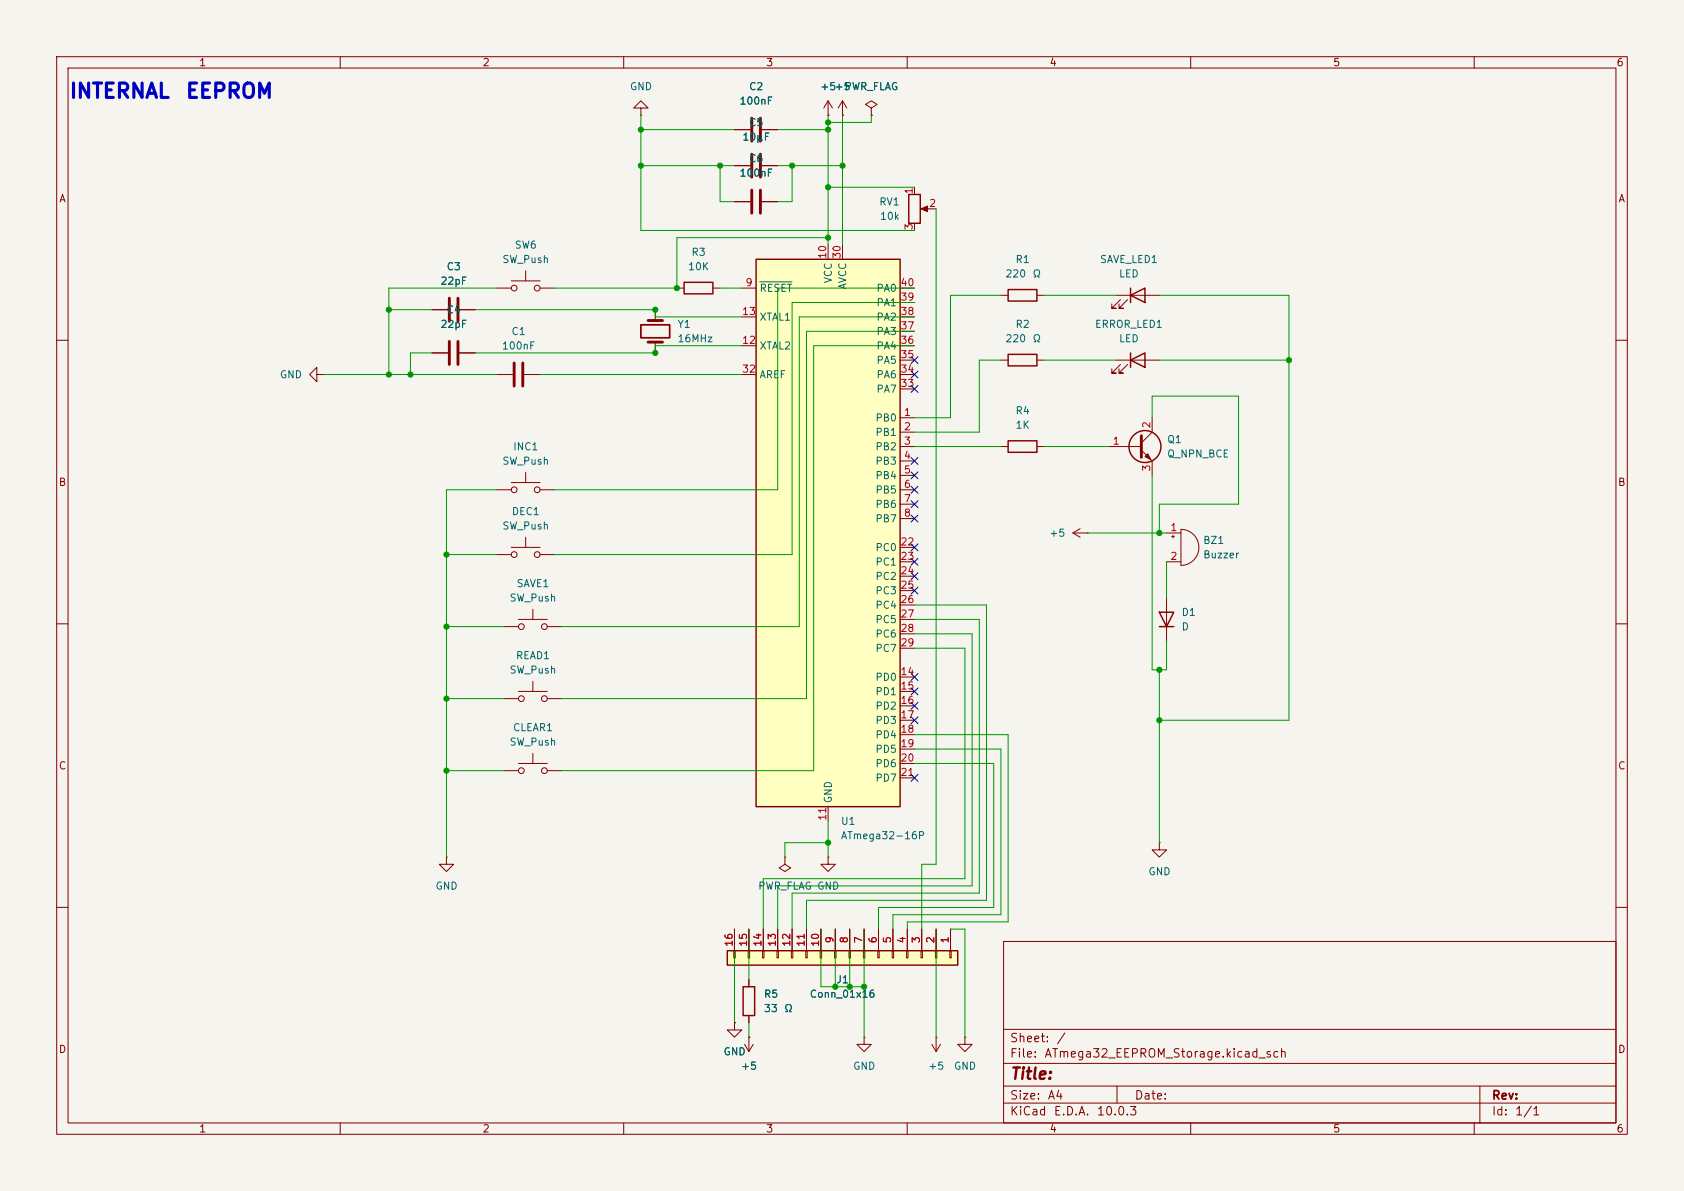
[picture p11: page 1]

Size: A4 | Rev:
KiCad E.D.A. 10.0.3 | Id: 1/1

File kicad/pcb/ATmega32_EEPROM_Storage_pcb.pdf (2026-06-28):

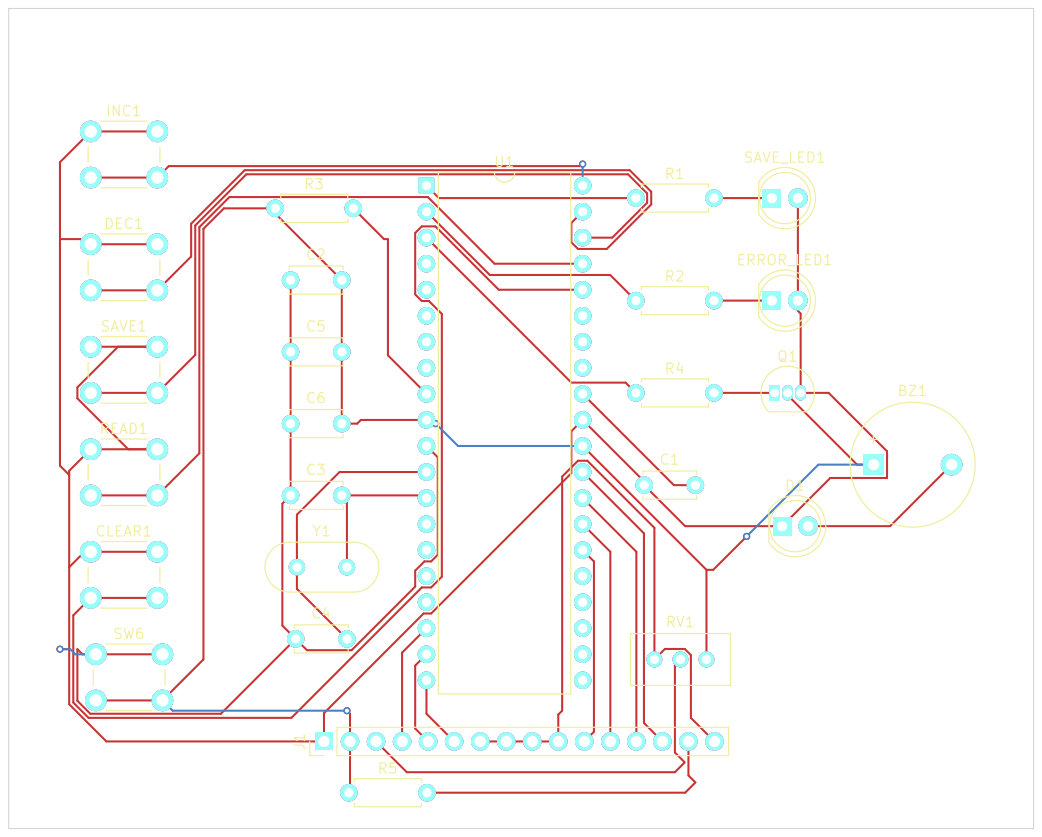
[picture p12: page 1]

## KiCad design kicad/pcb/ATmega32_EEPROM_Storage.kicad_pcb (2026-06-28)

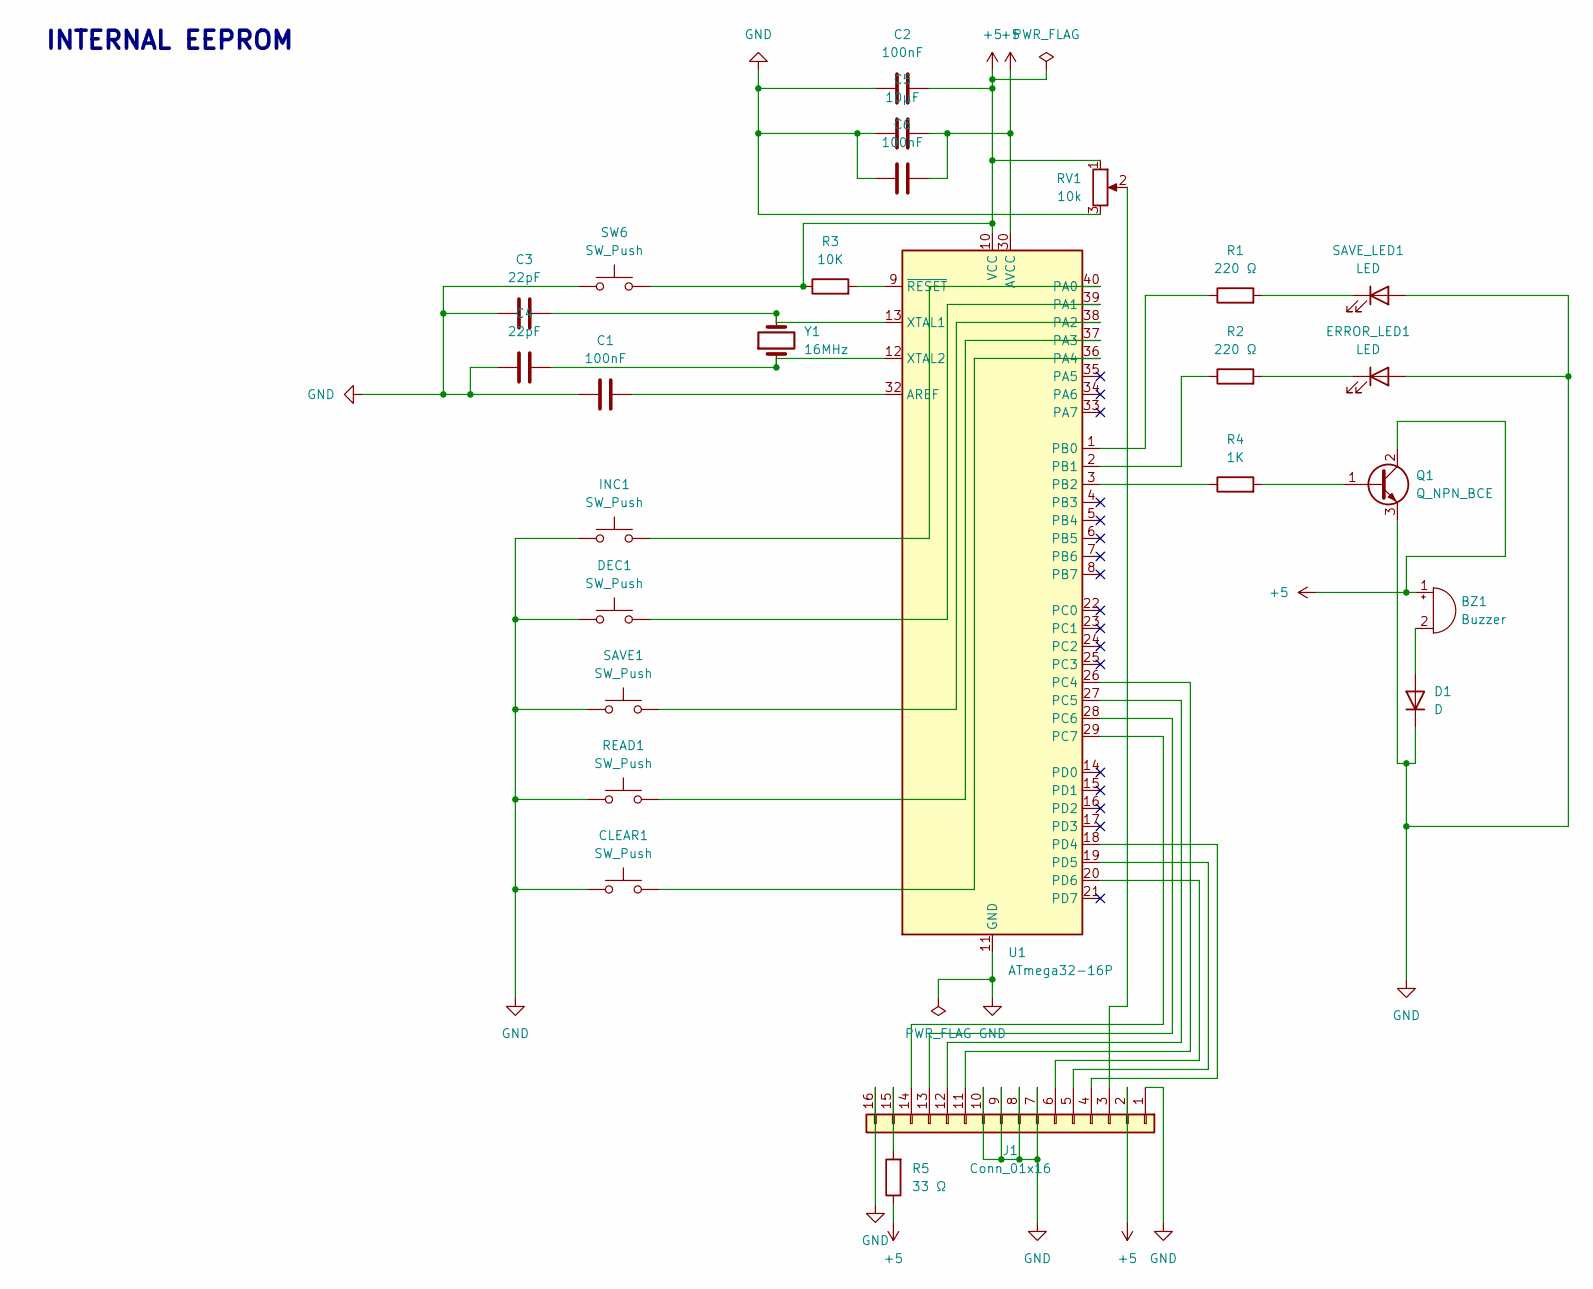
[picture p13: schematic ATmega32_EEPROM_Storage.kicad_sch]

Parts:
BZ1: Buzzer; Buzzer_12x9.5RM7.6
C1, C2, C6: 100nF; C_Disc_D5.0mm_W2.5mm_P5.00mm
C3, C4: 22pF; C_Disc_D5.0mm_W2.5mm_P5.00mm
C5: 10µF; C_Disc_D5.0mm_W2.5mm_P5.00mm
CLEAR1: SW_Push; SW_PUSH_6mm
D1: D; LED_D5.0mm
DEC1: SW_Push; SW_PUSH_6mm
ERROR_LED1: LED; LED_D5.0mm
INC1: SW_Push; SW_PUSH_6mm
J1: Conn_01x16; PinHeader_1x16_P2.54mm_Vertical
Q1: Q_NPN_BCE; TO-92_Inline
R1, R2: 220 Ω; R_Axial_DIN0207_L6.3mm_D2.5mm_P7.62mm_Horizontal
R3: 10K; R_Axial_DIN0207_L6.3mm_D2.5mm_P7.62mm_Horizontal
R4: 1K; R_Axial_DIN0207_L6.3mm_D2.5mm_P7.62mm_Horizontal
R5: 33 Ω; R_Axial_DIN0207_L6.3mm_D2.5mm_P7.62mm_Horizontal
READ1: SW_Push; SW_PUSH_6mm
RV1: 10k; Potentiometer_Bourns_3296W_Vertical
SAVE1: SW_Push; SW_PUSH_6mm
SAVE_LED1: LED; LED_D5.0mm
SW6: SW_Push; SW_PUSH_6mm
U1: ATmega32-16P; DIP-40_W15.24mm
Y1: 16MHz; Crystal_HC49-U_Vertical

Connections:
+5: BZ1.1 (+), C2.2, C5.2, C6.2, J1.2, Q1.2 (C), R3.1, R5.1, RV1.1, SW6.2, U1.10 (VCC), U1.30 (AVCC)
GND: C1.1, C2.1, C3.1, C4.1, C5.1, C6.1, CLEAR1.1, D1.1 (K), DEC1.1, ERROR_LED1.2 (A), INC1.1, J1.1, J1.7, J1.8, J1.9, J1.10, J1.16, Q1.3 (E), READ1.1, RV1.3, SAVE1.1, SAVE_LED1.2 (A), SW6.1, U1.11 (GND), U1.31 (GND)
unnamed: BZ1.2 (-), D1.2 (A)
unnamed: ERROR_LED1.1 (K), R2.2
unnamed: J1.3, RV1.2
unnamed: J1.4, U1.18 (PD4)
unnamed: J1.5, U1.19 (PD5)
unnamed: J1.6, U1.20 (PD6)
unnamed: J1.11, U1.26 (PC4)
unnamed: J1.12, U1.27 (PC5)
unnamed: J1.13, U1.28 (PC6)
unnamed: J1.14, U1.29 (PC7)
unnamed: J1.15, R5.2
unnamed: Q1.1 (B), R4.2
unnamed: R1.2, SAVE_LED1.1 (K)
unnamed: C1.2, U1.32 (AREF)
unnamed: INC1.2, U1.40 (PA0)
unnamed: DEC1.2, U1.39 (PA1)
unnamed: SAVE1.2, U1.38 (PA2)
unnamed: READ1.2, U1.37 (PA3)
unnamed: CLEAR1.2, U1.36 (PA4)
unnamed: R1.1, U1.1 (PB0)
unnamed: R2.1, U1.2 (PB1)
unnamed: R4.1, U1.3 (PB2)
unnamed: C3.2, U1.13 (XTAL1), Y1.2
unnamed: C4.2, U1.12 (XTAL2), Y1.1
unnamed: R3.2, U1.9 (~RESET)

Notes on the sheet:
INTERNAL EEPROM

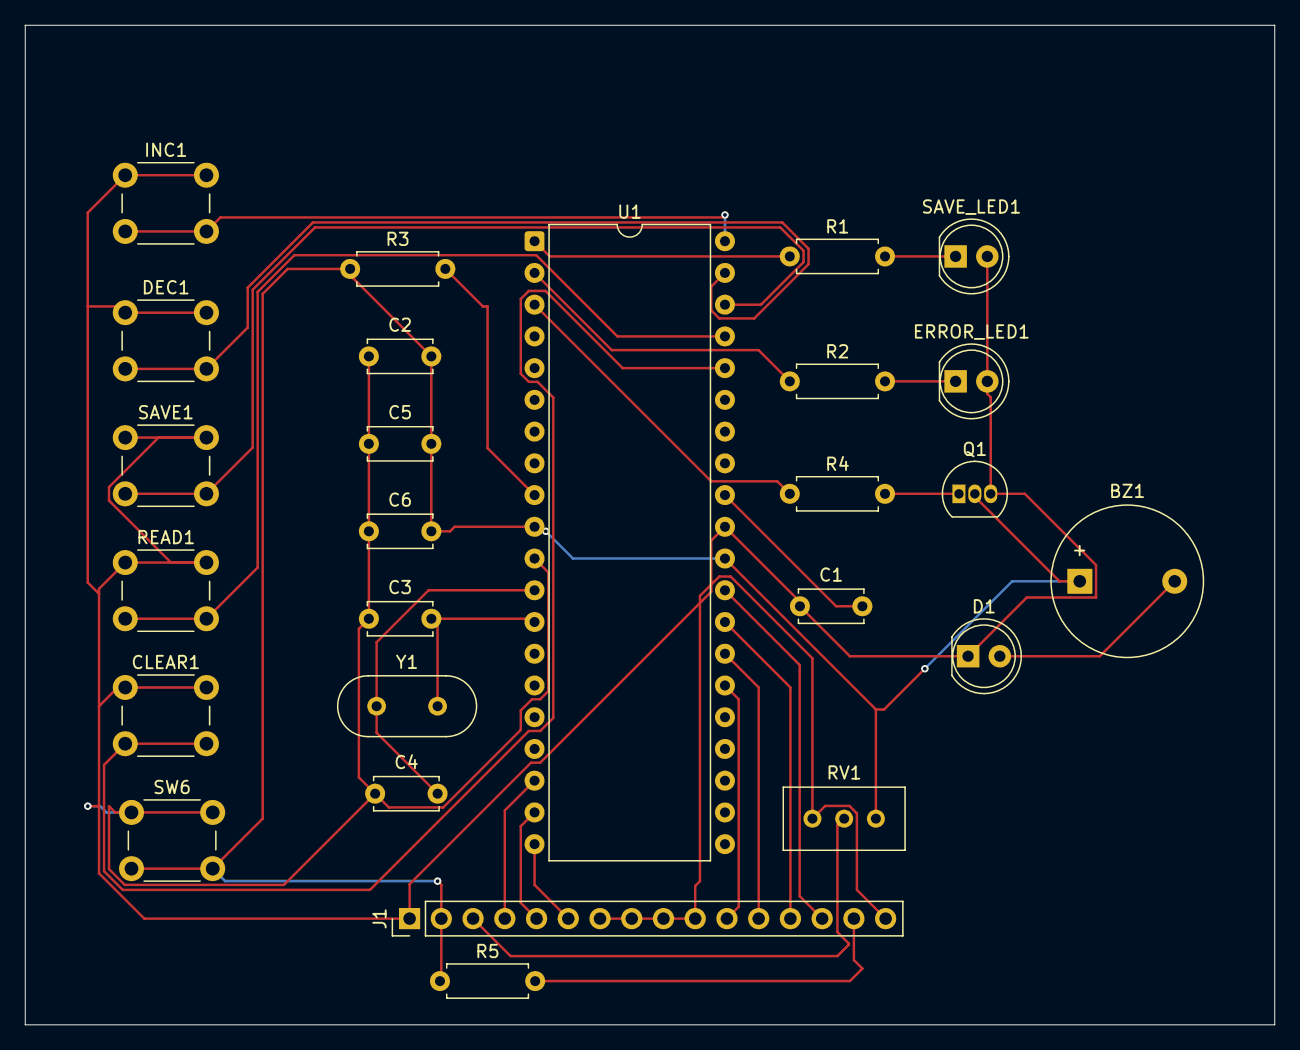
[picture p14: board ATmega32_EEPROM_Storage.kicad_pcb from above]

Board: 2 copper layers, 100.0 x 80.0 mm, 26 parts (0 on the bottom side), 27 nets.

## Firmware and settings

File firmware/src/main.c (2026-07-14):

/*
 * main.c
 * Project 16: EEPROM-Based Data Logging and Configuration Storage System
 *
 * Flow:
 *   Startup  -> reload current_value from its EEPROM auto-save slot and
 *               saved_value from the explicit SAVE slot, show CURRENT/SAVED
 *   Standby  -> poll the 5 buttons
 *   INC/DEC  -> adjust current_value in RAM (clamped to VALUE_MIN/VALUE_MAX)
 *               and immediately auto-save it to EEPROM, so the working
 *               value survives reset/power-cycling without pressing SAVE
 *   SAVE     -> write current_value to the explicit SAVED slot, confirm
 *               with LED + buzzer
 *   READ     -> re-read the explicit SAVED slot and show it as saved_value
 *   CLEAR    -> reset EEPROM (both slots) and current_value/saved_value to
 *               VALUE_DEFAULT
 *   Reset/Power-cycle -> EEPROM retains the last incremented/decremented
 *                        value, reloaded automatically on the next startup
 */

#include "config.h"
#include "eeprom_storage.h"
#include "button.h"
#include "indicator.h"
#include "display.h"

int main(void)
{
    unsigned char current_value;
    unsigned char saved_value;

    Indicator_Init();
    Button_Init();
    Display_Init();
    EEPROM_Storage_Init();

    /* Startup: current_value is the last auto-saved (incremented/decremented)
     * value, recovered without the user ever pressing SAVE; saved_value is
     * the last value explicitly written via the SAVE button. */
    current_value = EEPROM_LoadCurrentValue();
    saved_value = EEPROM_LoadValue();

    Display_ShowMessage("EEPROM STORAGE", "SYSTEM READY");
    Display_ShowValues(current_value, saved_value);

    for (;;) {
        Button_t pressed = Button_Scan();

        switch (pressed) {
            case BUTTON_INC:
                if (current_value < VALUE_MAX) {
                    current_value++;
                    EEPROM_SaveCurrentValue(current_value);
                    Display_ShowValues(current_value, saved_value);
                } else {
                    Indicator_Error(); /* already at maximum */
                }
                break;

            case BUTTON_DEC:
                if (current_value > VALUE_MIN) {
                    current_value--;
                    EEPROM_SaveCurrentValue(current_value);
                    Display_ShowValues(current_value, saved_value);
                } else {
                    Indicator_Error(); /* already at minimum */
                }
                break;

            case BUTTON_SAVE:
                EEPROM_SaveValue(current_value);
                saved_value = current_value;
                Indicator_SaveSuccess();
                Display_ShowValues(current_value, saved_value);
                break;

            case BUTTON_READ:
                saved_value = EEPROM_LoadValue();
                Display_ShowValues(current_value, saved_value);
                break;

            case BUTTON_CLEAR:
                EEPROM_ClearValue();
                current_value = VALUE_DEFAULT;
                saved_value = VALUE_DEFAULT;
                Indicator_ClearConfirm();
                Display_ShowValues(current_value, saved_value);
                break;

            case BUTTON_NONE:
            default:
                break;
        }
    }
}

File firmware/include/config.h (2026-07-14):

/*
 * config.h
 * Project 16: EEPROM-Based Data Logging and Configuration Storage System
 * Target: ATmega32, F_CPU = 8,000,000 Hz (internal/external clock, adjust if different)
 */

#ifndef CONFIG_H
#define CONFIG_H

#ifndef F_CPU
#define F_CPU 8000000UL
#endif

#include <avr/io.h>

/* ---------------------------------------------------------------------
 * Display backend selection
 * The project's KiCad schematic/PCB wires a 16-pin HD44780 LCD header
 * (J1) to PD4/PD5/PD6 (RS/RW/EN) and PC4-PC7 (D4-D7); PD0/PD1 (RXD/TXD)
 * are left unconnected on that board, so DISPLAY_MODE_LCD is the
 * correct default for the actual hardware. DISPLAY_MODE_USART remains
 * available for bench testing on a breadboard with a serial terminal.
 * --------------------------------------------------------------------- */
#define DISPLAY_MODE_USART 0
#define DISPLAY_MODE_LCD   1

#ifndef DISPLAY_MODE
#define DISPLAY_MODE DISPLAY_MODE_LCD
#endif

/* ---------------------------------------------------------------------
 * Push buttons - PORTA, active LOW (internal pull-ups enabled)
 * --------------------------------------------------------------------- */
#define BTN_PORT   PORTA
#define BTN_DDR    DDRA
#define BTN_PIN    PINA

#define BTN_INC    PA0   /* Increment button */
#define BTN_DEC    PA1   /* Decrement button */
#define BTN_SAVE   PA2   /* Save button      */
#define BTN_READ   PA3   /* Read button       */
#define BTN_CLEAR  PA4   /* Clear button      */

/* ---------------------------------------------------------------------
 * LEDs and buzzer - PORTB
 * --------------------------------------------------------------------- */
#define IND_PORT   PORTB
#define IND_DDR    DDRB

#define SAVE_LED   PB0   /* Save / status LED */
#define ERROR_LED  PB1   /* Error LED         */
#define BUZZER     PB2   /* Buzzer            */

/* ---------------------------------------------------------------------
 * EEPROM address map
 * --------------------------------------------------------------------- */
#define EEPROM_ADDR_MAGIC    0x00   /* marks EEPROM as initialized              */
#define EEPROM_ADDR_VALUE    0x01   /* explicitly saved value (SAVE button)     */
#define EEPROM_ADDR_CURRENT  0x02   /* auto-saved value (every INC/DEC press)   */
#define EEPROM_MAGIC_BYTE    0xAA   /* sentinel written after first save        */

/* ---------------------------------------------------------------------
 * Value limits
 * --------------------------------------------------------------------- */
#define VALUE_MIN     0
#define VALUE_MAX     255
#define VALUE_DEFAULT 0

/* ---------------------------------------------------------------------
 * Timing
 * --------------------------------------------------------------------- */
#define DEBOUNCE_DELAY_MS  25
#define BEEP_DELAY_MS      250
#define LED_PULSE_MS       400

#endif /* CONFIG_H */

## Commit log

2026-06-28 Added button control and LED/buzzer indicator firmware
2026-06-28 Added KiCad schematic design
    [ATmega32_EEPROM_Storage.kicad_sch]
2026-06-28 Added PCB layout and Gerber files
    [ATmega32_EEPROM_Storage-B_Courtyard.gbr, ATmega32_EEPROM_Storage-B_Cu.gbl, ATmega32_EEPROM_Storage-B_Fab.gbr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]
2026-06-28 Added SimulIDE simulation circuit and screenshots
2026-06-28 Added EEPROM test results, block diagram/flowchart, and project documentation
2026-07-18 Update action description for power state in README
